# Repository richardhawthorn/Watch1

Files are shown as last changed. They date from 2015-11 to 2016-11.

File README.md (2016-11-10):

### Description

An Arduino multimeter watch

### Multimeter functions

- Displays voltage between 0 and 30v
- Displays current upto 500mA
- Zener clamp and 500mA PTC to protect Arduino

### Features

- ATMEGA328P with Arduino boot-loader
- 3.3V operation with CR2032 battery
- 32.768kHz crystal
- Mini 7 segment display
- 2x side buttons for menu operation
- FTDI programming port
- Low power operation

### Bootloader

You will need to set various fuses when you upload the bootloader, thse can be done with this command

avrdude -b 19200 -c usbtiny -p m328p -v -e -U lfuse:w:0xe2:m -U hfuse:w:0xda:m -U efuse:w:0x07:m

### License

This work is licensed under a Creative Commons Attribution-ShareAlike 4.0 International License.

<br />
Designed by <a xmlns:cc="http://creativecommons.org/ns#" href="http://www.richardhawthorn.com" property="cc:attributionName" rel="cc:attributionURL" target="_blank">Richard Hawthorn</a><br />
<a rel="license" href="http://creativecommons.org/licenses/by-sa/4.0/" target="_blank">View License</a>

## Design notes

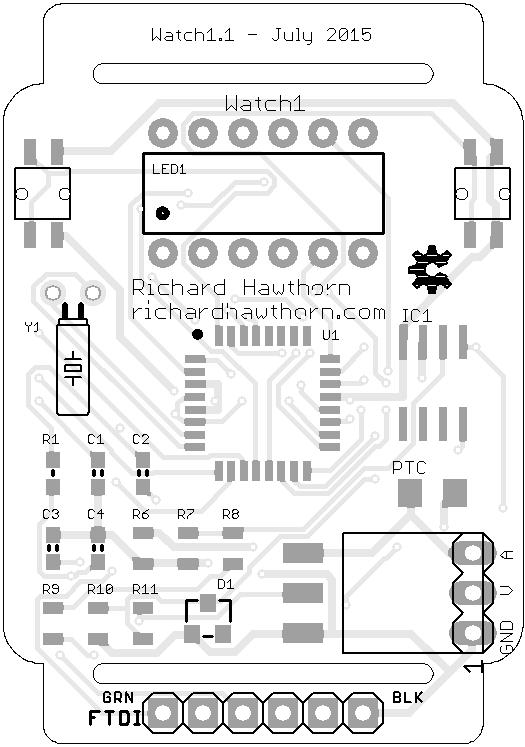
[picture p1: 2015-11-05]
images/pcb_front.png

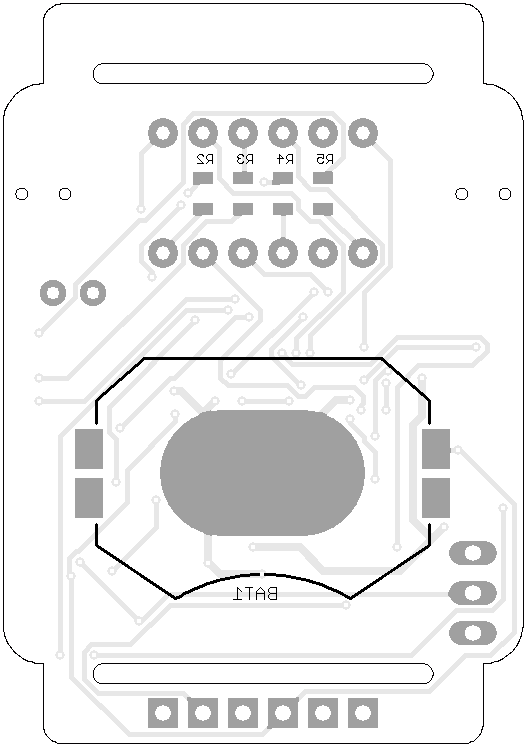
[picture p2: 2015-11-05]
images/pcb_back.png

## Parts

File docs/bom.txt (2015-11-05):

Qty Value          Device                      Package                      Parts          Description                                                                         
1                  MA03-1                      MA03-1                       CN1            PIN HEADER                                                                          
2                  TURTLE-3PIN                 TURTLE-3PIN                  BTN1, BTN2     Buttons                                                                                    
2   0.1            CAP0603-CAP                 0603-CAP                     C1, C2         Capacitor                                                                           
1   0.1uf          CAP0603-CAP                 0603-CAP                     C3             Capacitor                                                                           
1   10k            RESISTOR0603-RES            0603-RES                     R1             Resistor                                                                            
1   10k            RESISTOR0805                0805                         R11            Resistor                                                                            
1   10uf           CAP0603-CAP                 0603-CAP                     C4             Capacitor                                                                           
1   12k            RESISTOR0805                0805                         R8             Resistor                                                                            
2   1k5            RESISTOR0805                0805                         R7, R9         Resistor                                                                            
1   1r             RESISTOR0805                0805                         R6             Resistor                                                                            
1   20mm coincell  BATTERY20MM	               BATTCON_20MM                 BAT1           Battery Holders                                                                     
1   2k             RESISTOR0805                0805                         R10            Resistor                                                                            
1   32.768kHz      CRYSTALTC26H_EZ             TC26HEZ                      Y1             Spark Fun Electronics SKU : COM-00534 
4   330r           RESISTOR0805                0805                         R2, R3, R4, R5 Resistor                                                                            
1   3PIN-HEADER-RA 3PIN-HEADER-RA              3PIN_HEAD_RA                 CN2            3 pin right angle header                                                            
1   500ma          R-US_R1206                  R1206                        PTC            RESISTOR, American symbol                                                           
1   ATMega-328     ATMEGA168/328TQFP32         TQFP32-08                    U1             Atmel 32-pin 8-bit micro, 16k flash.                                                
1   BZX84CSMD      BZX84CSMD                   TO236                        D1             Z DIODE                                                                             
1   FTDI           PINHD-1X6                   1X06                         CN4            PIN HEADER                                                                          
1   HP_DISPLAY     HP_DISPLAY                  DIL12                        LED1           7 Segment LED screen                                                                                    
1   LM358D         LM358D                      SO08                         IC1            OP AMP also LM158; LM258; LM2904

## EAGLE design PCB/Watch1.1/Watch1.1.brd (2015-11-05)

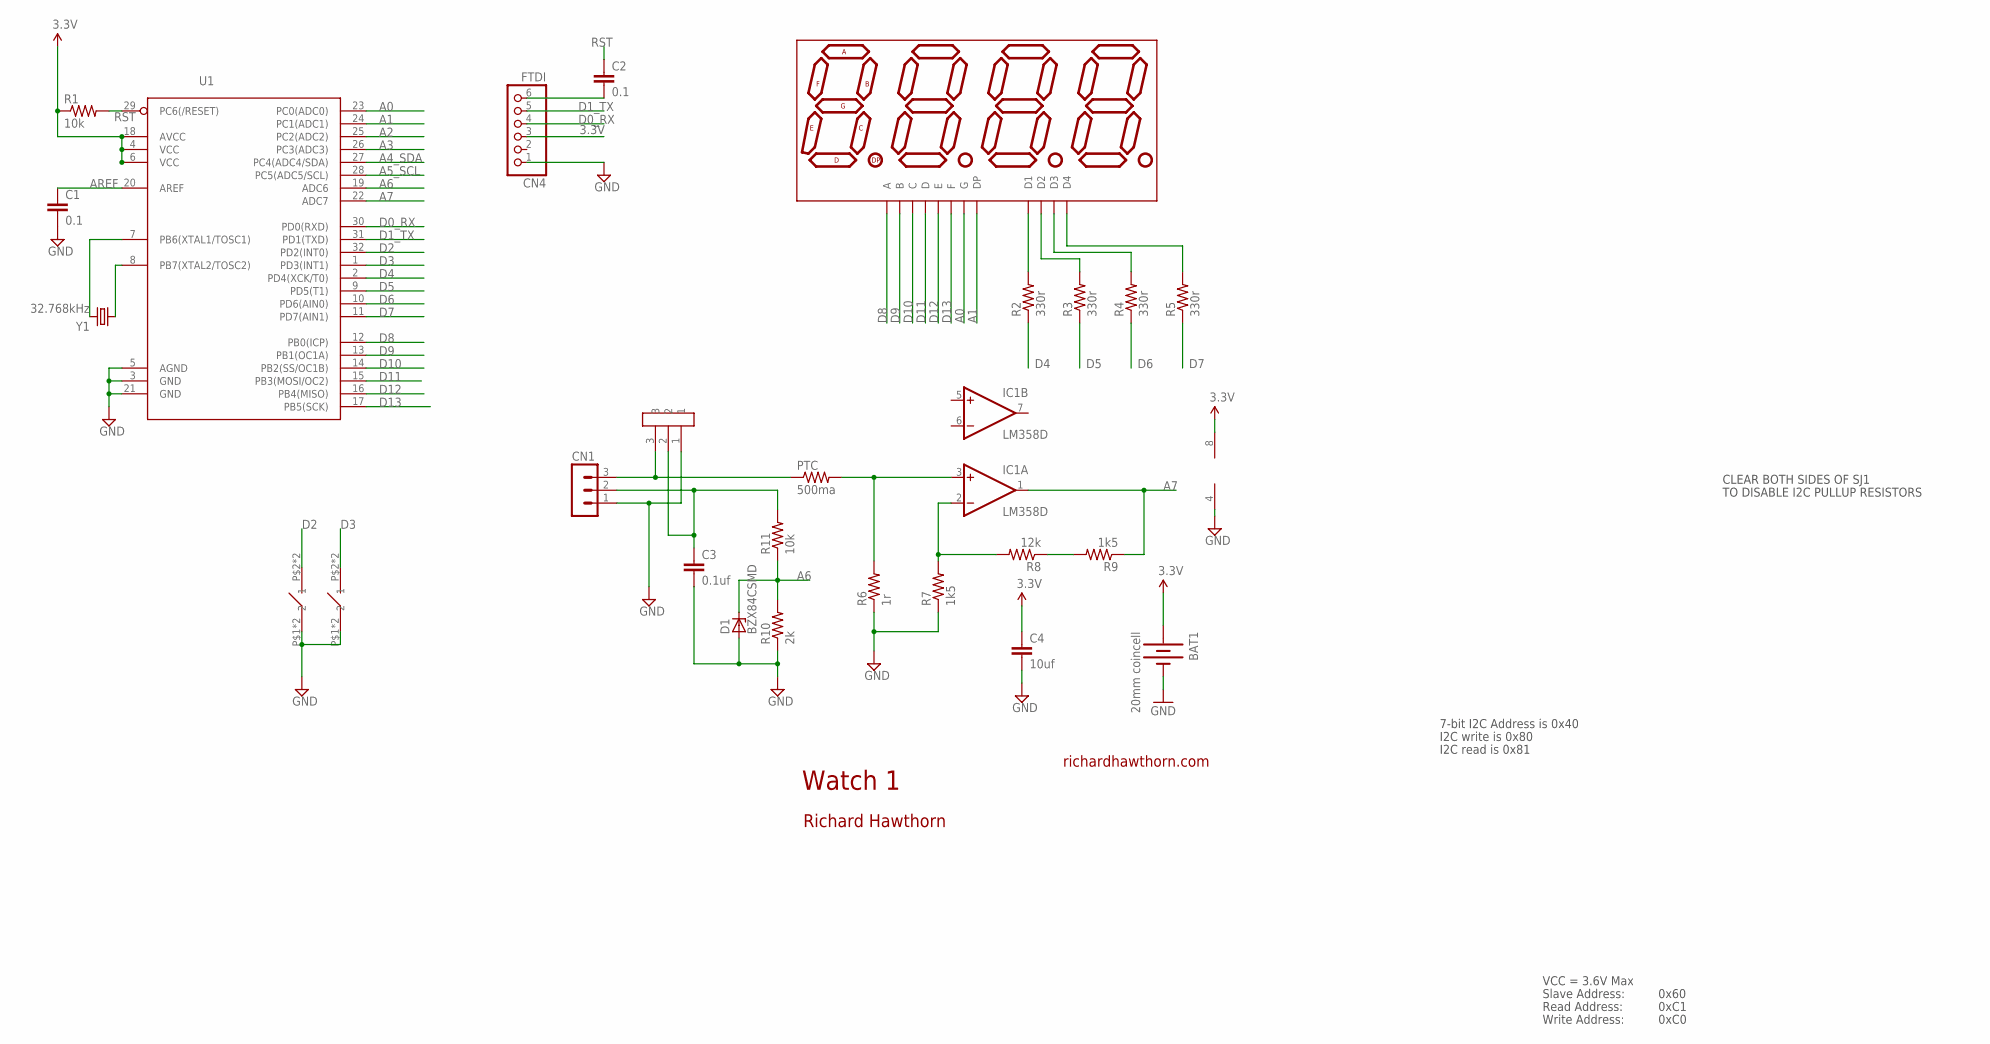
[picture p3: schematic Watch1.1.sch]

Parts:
BAT1: 20mm coincell; BATTCON_20MM_4LEGS_OVERPASTE
BTN1, BTN2: TURTLE-3PIN
C1, C2: 0.1; 0603-CAP
C3: 0.1uf; 0603-CAP
C4: 10uf; 0603-CAP
CN1: MA03-1
CN2: 3PIN-HEADER-RA; 3PIN_HEAD_RA
CN4: FTDI; 1X06
D1: BZX84CSMD; TO236
IC1: LM358D; SO08
LED1: HP_DISPLAY; DIL12
PTC: 500ma; R1206
R1: 10k; 0603-RES
R2, R3, R4, R5: 330r; 0805
R6: 1r; 0805
R7, R9: 1k5; 0805
R8: 12k; 0805
R10: 2k; 0805
R11: 10k; 0805
U1: ATMega-328; TQFP32-08
Y1: 32.768kHz; TC26HEZ

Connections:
3.3V: BAT1.1 (+), C4.1, CN4.3, IC1.8 (V+), R1.1, U1.4 (VCC), U1.6 (VCC), U1.18 (AVCC)
A0: LED1.7 (G), U1.23 (PC0(ADC0))
A1: LED1.5 (DP), U1.24 (PC1(ADC1))
A2: U1.25 (PC2(ADC2))
A3: U1.26 (PC3(ADC3))
A4_SDA: U1.27 (PC4(ADC4/SDA))
A5_SCL: U1.28 (PC5(ADC5/SCL))
A6: D1.C, R10.2, R11.1, U1.19 (ADC6)
A7: IC1.1 (OUT), R9.1, U1.22 (ADC7)
AREF: C1.1, U1.20 (AREF)
D0_RX: CN4.4, U1.30 (PD0(RXD))
D1_TX: CN4.5, U1.31 (PD1(TXD))
D2: BTN1.P$2 (2), BTN1.P$4 (2), U1.32 (PD2(INT0))
D3: BTN2.P$2 (2), BTN2.P$4 (2), U1.1 (PD3(INT1))
D4: R2.1, U1.2 (PD4(XCK/T0))
D5: R3.1, U1.9 (PD5(T1))
D6: R4.1, U1.10 (PD6(AIN0))
D7: R5.1, U1.11 (PD7(AIN1))
D8: LED1.12 (A), U1.12 (PB0(ICP))
D9: LED1.11 (B), U1.13 (PB1(OC1A))
D10: LED1.3 (C), U1.14 (PB2(SS/OC1B))
D11: LED1.8 (D), U1.15 (PB3(MOSI/OC2))
D12: LED1.2 (E), U1.16 (PB4(MISO))
D13: LED1.9 (F), U1.17 (PB5(SCK))
GND: BAT1.2 (-), BTN1.P$1 (1), BTN1.P$3 (1), BTN2.P$1 (1), BTN2.P$3 (1), C1.2, C3.2, C4.2, CN1.1, CN2.1, CN4.1, D1.A, IC1.4 (V-), R6.1, R7.1, R10.1, U1.3 (GND), U1.5 (AGND), U1.21 (GND)
unnamed: U1.7 (PB6(XTAL1/TOSC1)), Y1.2
unnamed: LED1.1 (D1), R2.2
unnamed: LED1.10 (D2), R3.2
unnamed: LED1.4 (D3), R4.2
unnamed: LED1.6 (D4), R5.2
unnamed: CN1.3, CN2.3, PTC.1
unnamed: IC1.3 (+IN), PTC.2, R6.2
unnamed: IC1.2 (-IN), R7.2, R8.2
unnamed: R8.1, R9.2
unnamed: U1.8 (PB7(XTAL2/TOSC2)), Y1.1
unnamed: C3.1, CN1.2, CN2.2, R11.2
unnamed: C2.2, CN4.6
RST: C2.1, R1.2, U1.29 (PC6(/RESET))

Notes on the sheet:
Watch 1
richardhawthorn.com
Richard Hawthorn
CLEAR BOTH SIDES OF SJ1
TO DISABLE I2C PULLUP RESISTORS
7-bit I2C Address is 0x40
I2C write is 0x80
I2C read is 0x81
VCC = 3.6V Max
Read Address:
Write Address:
Slave Address:
0x60
0xC1
0xC0

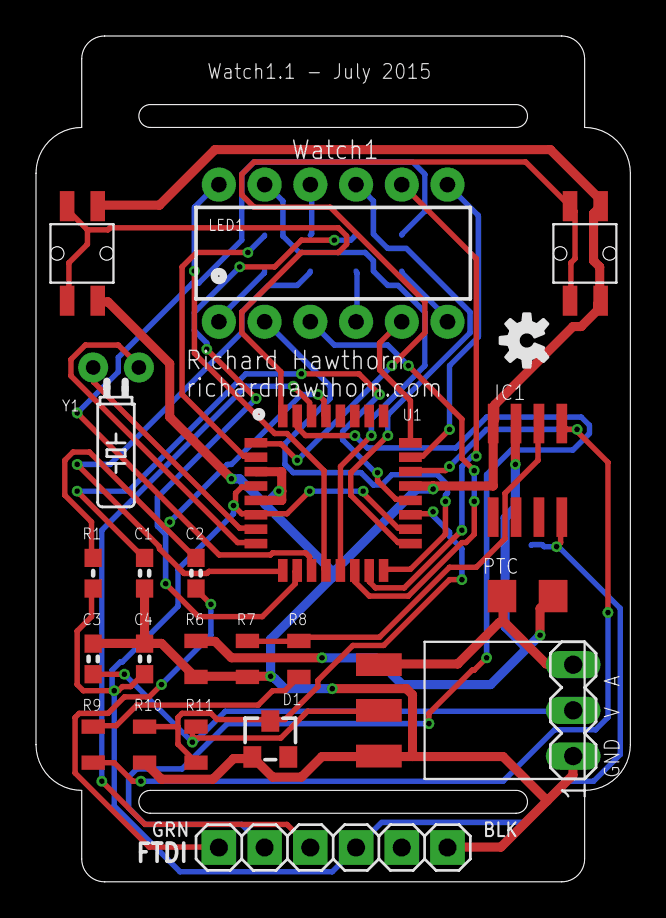
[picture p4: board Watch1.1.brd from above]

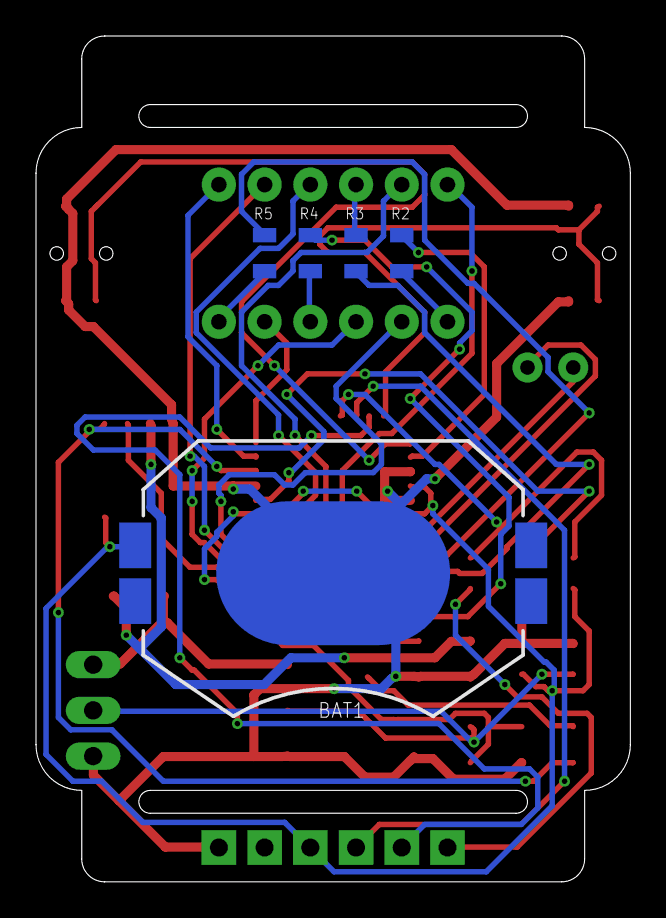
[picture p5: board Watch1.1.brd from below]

Board: 2 copper layers, 33.0 x 47.0 mm, 28 parts (5 on the bottom side), 34 nets.

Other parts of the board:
U$3: OSHW-LOGO-S

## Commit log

2015-07-04 First version of the watch
    [Watch1.1.brd, Watch1.1.sch]
2015-07-05 fix diode position
    [Watch1.1.brd, Watch1.1.sch]
2015-11-05 updated readme and added pcb images
2015-11-05 added bom

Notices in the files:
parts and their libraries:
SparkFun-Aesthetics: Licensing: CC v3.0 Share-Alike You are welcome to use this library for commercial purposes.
